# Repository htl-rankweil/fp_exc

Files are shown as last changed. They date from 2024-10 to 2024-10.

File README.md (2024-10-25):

  

# `EXC` - EXtendable Controller (Erweiterbarer Mikrocontroller)

The `EXC` is a microcontroller board with an [ATmega16A](#additional-information)/[ATmega164A](#additional-information). The Board can be powerd over USB or from an external Source (`9-15V`) and used with common Voltages of `3V3` or `5V`. Over the USB port it is also possible to establish a serial (`uart`) connection to a computer. The Board itself offers a `SPI`, `I2C` interface for bus systems, a interface for connection to external interrupts of the microcontroller and a analog interface for reading analog data into the microcontroller. At `DP1` a [Display](#additional-information) can be connected to the board. The available demo firmware offers a quick demonstartion of the board functionallity. Check the [Software](#software) section to get more information.

| Experience | Level |
|:---|:-----:|
| Soldering | ?% |
| Software | ?% |

# Downloads

| Type | File | Description |
|:---:|:---:|:---|
| Schematic | [pdf](https://github.com/0x007E/exc/releases/latest/download/schematic.pdf) / [cadlab](https://cadlab.io/project/28573/main/files) | Schematic files |
| Board | [pdf](https://github.com/0x007E/exc/releases/latest/download/pcb.pdf) / [cadlab](https://cadlab.io/project/28573/main/files) | Board file |
| Drill | [pdf](https://github.com/0x007E/exc/releases/latest/download/drill.pdf) | Drill file |
| Gerber | [zip](https://github.com/0x007E/exc/releases/latest/download/kicad.zip) / [tar](https://github.com/0x007E/exc/releases/latest/download/kicad.tar.gz) | Gerber/Drill files |
| Firmware | [zip](https://github.com/0x007E/exc/releases/latest/download/firmware.zip) / [tar](https://github.com/0x007E/exc/releases/latest/download/firmware.tar.gz) | Firmware for ATmega164A |

# Hardware

The pcb is created with `KiCAD`. All files are built with `github actions` so that they are ready for a production environment.

## PCB

The circuit board is populated on one side. The best way for soldering is within a vapor phase soldering system.

### Top Layer

Top Layer

### Bottom Layer

Bottom Layer

# Configuration

With Jumper `J13` the `EXC` system is getting bus powered (`5V`). If the system runs with `5V` jumper `J12` has to be shorten between `2-3`. When the system is driven by an external source through the step-down converter the system voltage is switchable between `5V` and `3V3` over the slider switch `SW6`. If `3V3` are choosen the jumper `J12` should be shorten between `1-2`.

> Only change the state of `SW6` with disconnected power source. Also check if jumper `J12` is set correctly!

## LEDs/I2C

To enable the LEDs `LED0-1` jumper `J10` has to be shorten. If the `I2C` interface should be used the jumper `J10` has to be removed.

## UART

The UART of the `ATmega164A` can be coupled with the USB/UART bridge or with the external UART interface at connector `J5`. To set the transmission over USB/UART bridge jumper `J1` and `J2` should be shorten between `1-2`. For the external UART interface jumper `J1` and `J2` should be shorten between `2-3`.

## Display

The display can be powerd constantly over `J99` shorten between `2-3` or controllabe over the microcontroller pin `PA2` and `J99` shorten between `1-2`.

# Programming

The Firmware of the `EXC` can be programmed with [Microchip Studio](#additional-information) over ISP with an [ATMEL ICE](#additional-information) connected to `J9` of the `EXC`. It is necessary to power the board from outside either over USB or the external power supply during programming.

## FUSES

| Register  | Value  |
|:---:|:---:|
| `HIGH` | `0xD8` |
| `LOW` | `0xFF` |

# Software

## Dataflow diagram

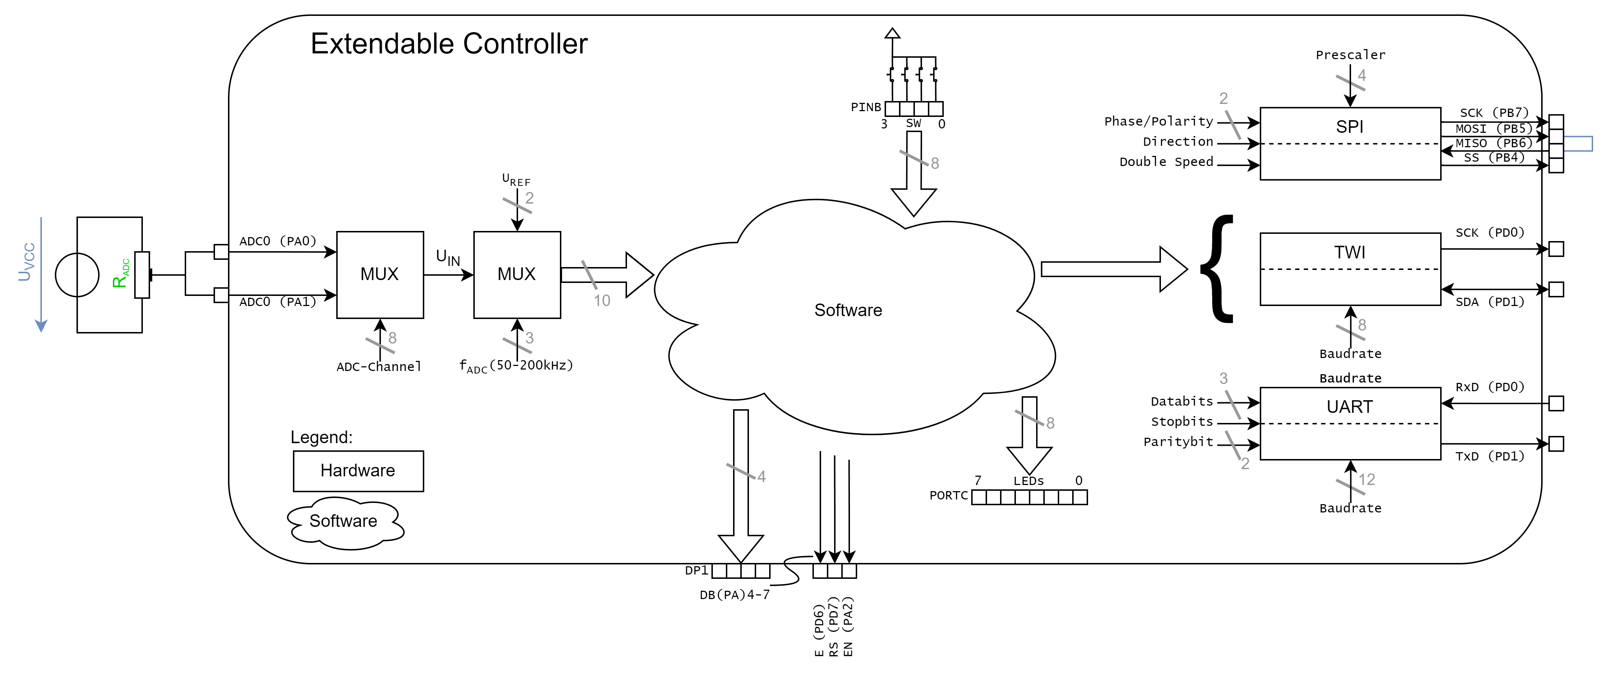
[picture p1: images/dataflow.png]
Dataflow


## Structogram

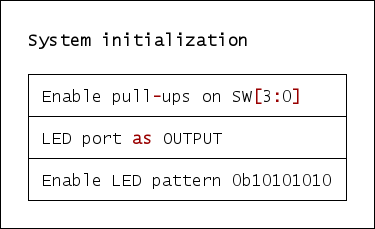
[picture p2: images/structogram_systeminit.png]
Structogram


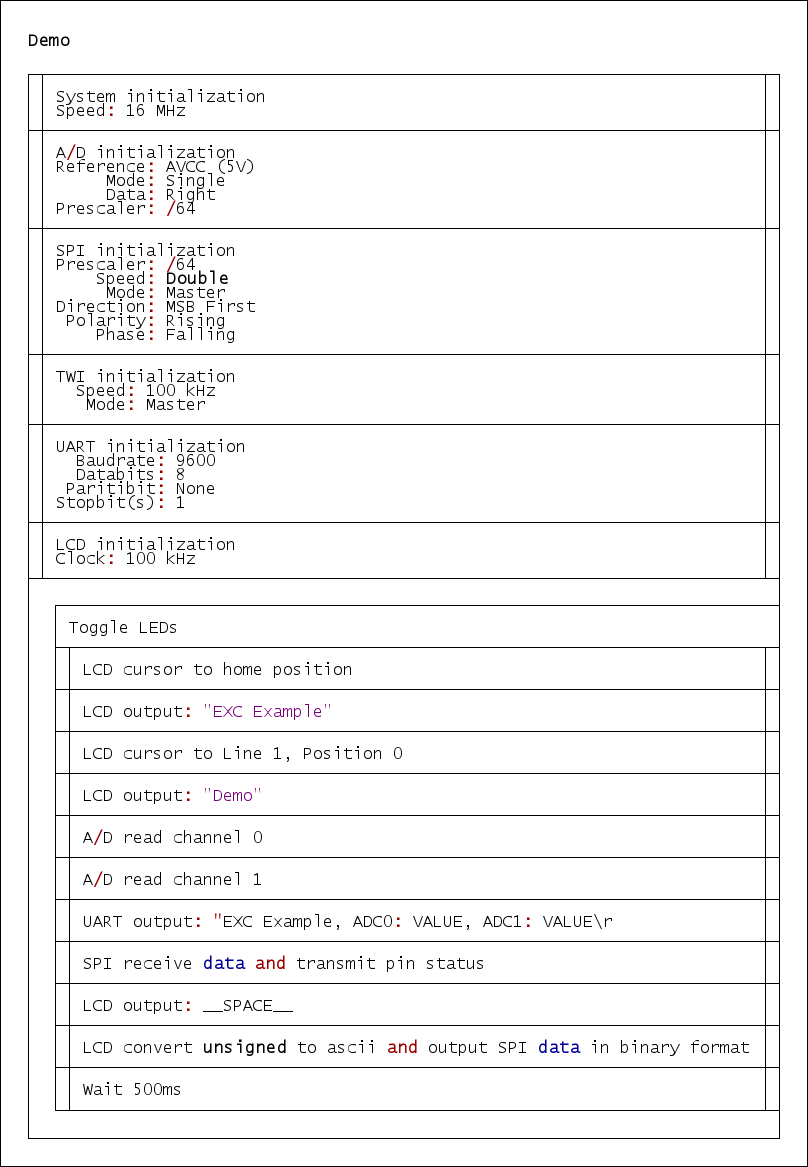
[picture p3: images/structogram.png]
Structogram


# Additional Information

| Type | Link | Description |
|:---:|:---:|:---|
| Display | [web](https://at.rs-online.com/web/p/lcd-displays-monochrom/5326385) | Display for extendable controller |
| Microchip Studio | [web](https://www.microchip.com/en-us/tools-resources/develop/microchip-studio) | Download Page for Microchip Studio |
| Atmel ICE | [pdf](https://ww1.microchip.com/downloads/en/DeviceDoc/Atmel-ICE_UserGuide.pdf) | Atmel ICE Datasheet |
| ATmega16A | [pdf](https://ww1.microchip.com/downloads/en/devicedoc/atmel-8154-8-bit-avr-atmega16a_datasheet.pdf) | Microchip ATmega16A Datasheet
| ATmega164A | [pdf](https://ww1.microchip.com/downloads/en/devicedoc/atmel-8272-8-bit-avr-microcontroller-atmega164a_pa-324a_pa-644a_pa-1284_p_datasheet.pdf) | Microchip ATmega164A Datasheet |

---

R. GAECHTER

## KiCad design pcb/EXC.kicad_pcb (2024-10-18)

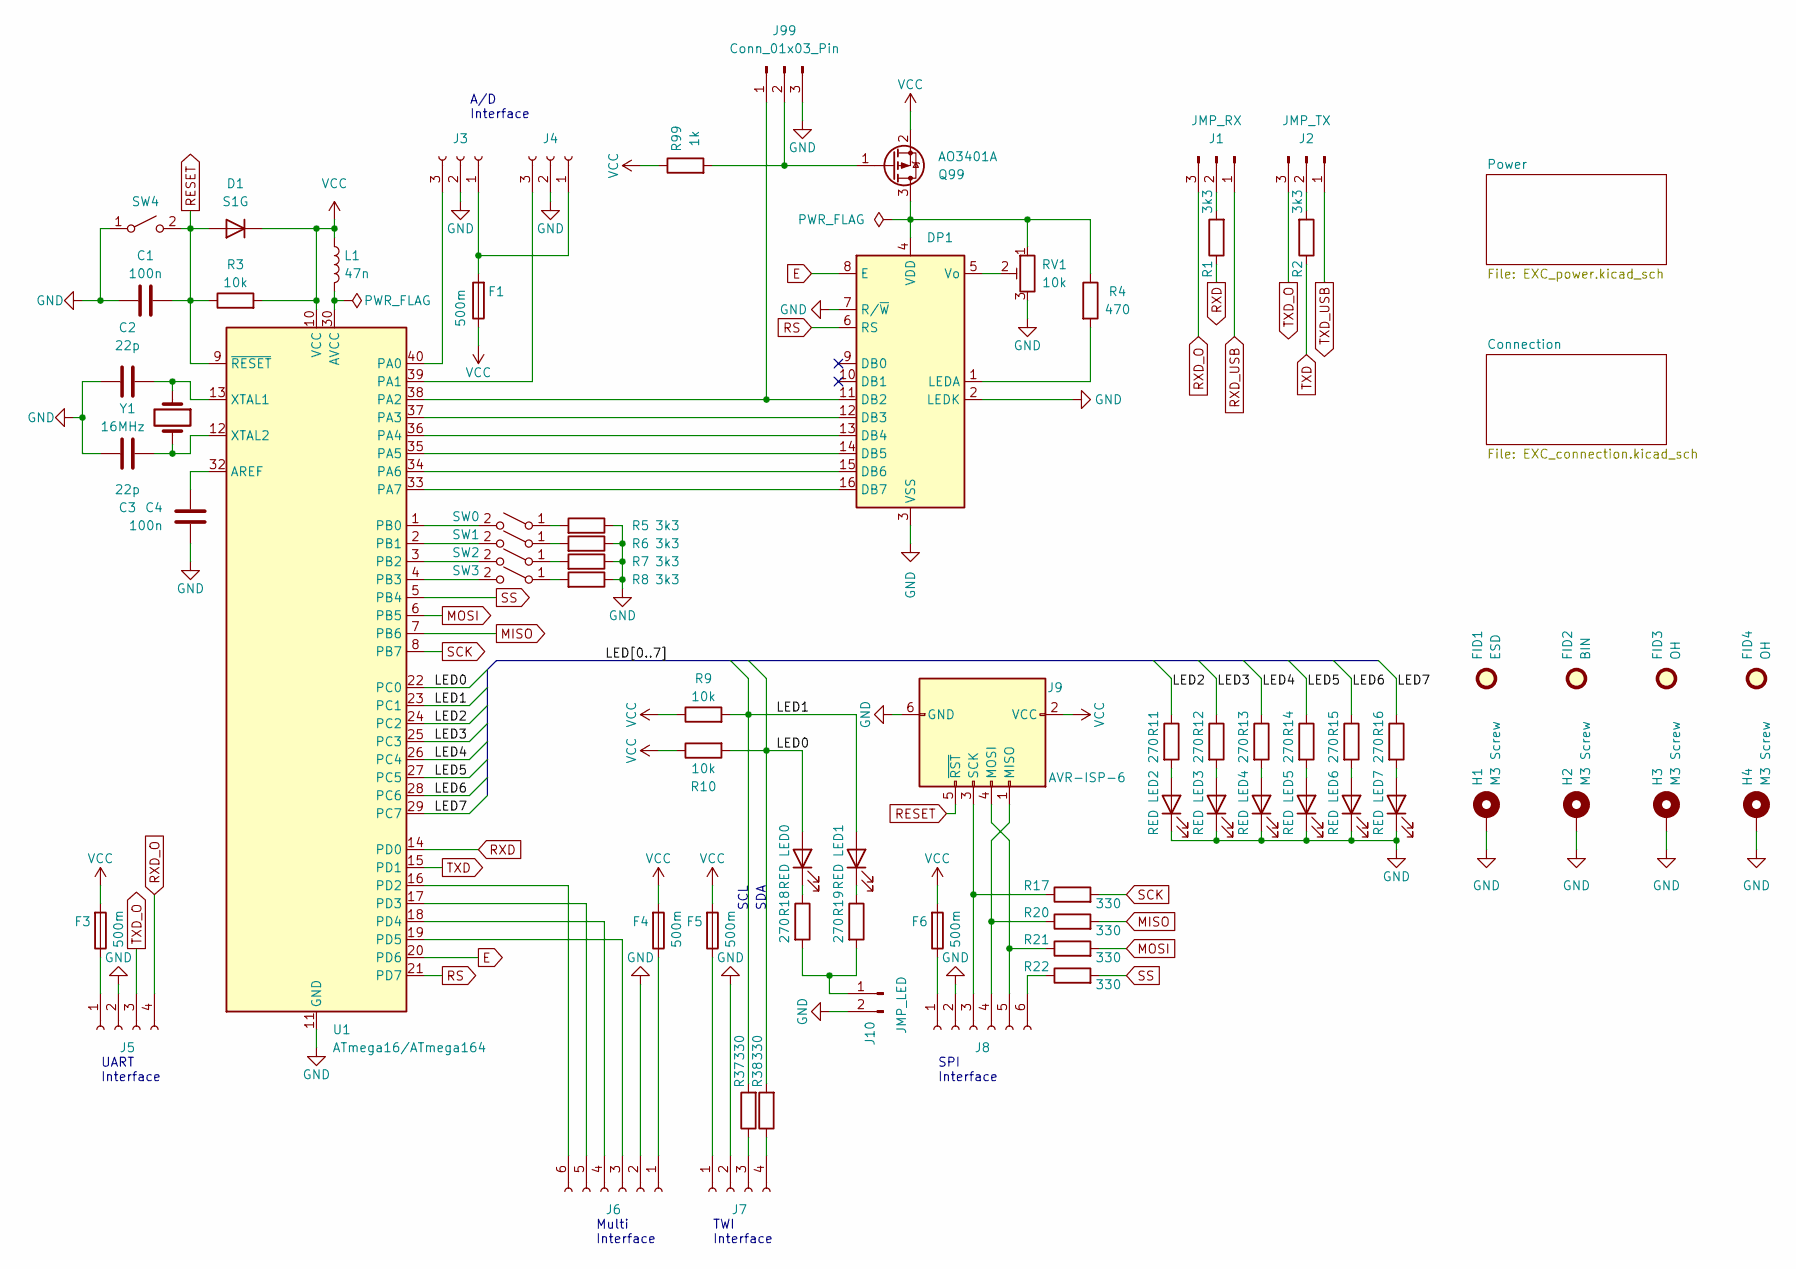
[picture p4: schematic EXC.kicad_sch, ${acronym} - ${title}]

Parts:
C1, C4: 100n; C_1206_3216Metric
C2, C3: 22p; C_1206_3216Metric
D1: S1G; D_MiniMELF
DP1: Displaytech_162A_THT
F1, F3, F4, F5, F6: 500m; Fuse_1206_3216Metric
FID1: ESD; ESD-Logo_6.6x6mm_SilkScreen
FID2: BIN; WEEE-Logo_4.2x6mm_SilkScreen
FID3: OH; OSHW-Logo_5.7x6mm_SilkScreen
FID4: OH; QR_0x007e
H1, H2, H3, H4: M3 Screw; MountingHole_3.2mm_M3_DIN965_Pad
J1: JMP_RX; PinHeader_1x03_P2.54mm_Vertical
J2: JMP_TX; PinHeader_1x03_P2.54mm_Vertical
J3, J4: Conn_01x03_Socket; PinSocket_1x03_P2.54mm_Vertical
J5, J7: Conn_01x04_Socket; PinSocket_1x04_P2.54mm_Vertical
J6, J8: Conn_01x06_Socket; PinSocket_1x06_P2.54mm_Vertical
J9: AVR-ISP-6; PinHeader_2x03_P2.54mm_Vertical
J10: JMP_LED; PinHeader_1x02_P2.54mm_Vertical
J99: Conn_01x03_Pin; PinHeader_1x03_P2.54mm_Horizontal
L1: 47n; L_1206_3216Metric_Pad1.42x1.75mm_HandSolder
LED0, LED1, LED2, LED3, LED4, LED5, LED6, LED7: RED; LED_1206_3216Metric
Q99: AO3401A; SOT-23
R1, R2, R5, R6, R7, R8: 3k3; R_1206_3216Metric
R3, R9, R10: 10k; R_1206_3216Metric
R4: 470; R_1206_3216Metric
R11, R12, R13, R14, R15, R16, R18, R19: 270; R_1206_3216Metric
R17, R20, R21, R22, R37, R38: 330; R_1206_3216Metric
R99: 1k; R_1206_3216Metric
RV1: 10k; Potentiometer_Bourns_3266W_Vertical
SW0, SW1, SW2, SW3, SW4: SW_SPST; SW_SPST_PTS645
U1: ATmega16/ATmega164; DIP-40_W15.24mm_LongPads
Y1: 16MHz; Crystal_SMD_Abracon_ABM3-2Pin_5.0x3.2mm

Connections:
/LED0: LED0.2 (A), R10.2, R38.2, U1.22 (PC0)
/LED1: LED1.2 (A), R9.2, R37.2, U1.23 (PC1)
/LED2: R11.1, U1.24 (PC2)
/LED3: R12.1, U1.25 (PC3)
/LED4: R13.1, U1.26 (PC4)
/LED5: R14.1, U1.27 (PC5)
/LED6: R15.1, U1.28 (PC6)
/LED7: R16.1, U1.29 (PC7)
E: DP1.8 (E), U1.20 (PD6)
GND: C1.1, C2.1, C3.1, C4.2, DP1.2 (LEDK), DP1.3 (VSS), DP1.7 (R/~W), H1.1, H2.1, H3.1, H4.1, J3.2, J4.2, J5.2, J6.2, J7.2, J8.2, J9.6 (GND), J10.2, J99.3, LED2.1 (K), LED3.1 (K), LED4.1 (K), LED5.1 (K), LED6.1 (K), LED7.1 (K), R5.1, R6.1, R7.1, R8.1, RV1.3, SW4.1 (A), U1.11 (GND), U1.31 (GND); also elsewhere on the board
MISO: R20.2, U1.7 (PB6)
MOSI: R21.2, U1.6 (PB5)
unnamed: DP1.11 (DB2), J99.1, U1.38 (PA2)
unnamed: DP1.12 (DB3), U1.37 (PA3)
unnamed: DP1.13 (DB4), U1.36 (PA4)
unnamed: DP1.14 (DB5), U1.35 (PA5)
unnamed: DP1.15 (DB6), U1.34 (PA6)
unnamed: DP1.16 (DB7), U1.33 (PA7)
unnamed: DP1.1 (LEDA), R4.2
unnamed: DP1.4 (VDD), Q99.3 (D), R4.1, RV1.1
unnamed: DP1.5 (Vo), RV1.2
unnamed: J1.2, R1.2
unnamed: J2.2, R2.2
unnamed: F1.2, J3.1, J4.1
unnamed: J3.3, U1.40 (PA0)
unnamed: J4.3, U1.39 (PA1)
unnamed: F3.1, J5.1
unnamed: F4.1, J6.1
unnamed: J6.3, U1.19 (PD5)
unnamed: J6.4, U1.18 (PD4)
unnamed: J6.5, U1.17 (PD3)
unnamed: J6.6, U1.16 (PD2)
unnamed: F5.1, J7.1
unnamed: J7.3, R37.1
unnamed: J7.4, R38.1
unnamed: F6.1, J8.1
unnamed: J8.3, J9.3 (SCK), R17.1
unnamed: J8.4, J9.1 (MISO), R20.1
unnamed: J8.5, J9.4 (MOSI), R21.1
unnamed: J8.6, R22.1
unnamed: J10.1, R18.2, R19.2
unnamed: J99.2, Q99.1 (G), R99.2
unnamed: LED0.1 (K), R18.1
unnamed: LED1.1 (K), R19.1
unnamed: LED2.2 (A), R11.2
unnamed: LED3.2 (A), R12.2
unnamed: LED4.2 (A), R13.2
unnamed: LED5.2 (A), R14.2
unnamed: LED6.2 (A), R15.2
unnamed: LED7.2 (A), R16.2
unnamed: R5.2, SW0.1 (A)
unnamed: SW0.2 (B), U1.1 (PB0)
unnamed: R6.2, SW1.1 (A)
unnamed: SW1.2 (B), U1.2 (PB1)
unnamed: R7.2, SW2.1 (A)
unnamed: SW2.2 (B), U1.3 (PB2)
unnamed: R8.2, SW3.1 (A)
unnamed: SW3.2 (B), U1.4 (PB3)
unnamed: C4.1, U1.32 (AREF)
unnamed: L1.2, U1.30 (AVCC)
unnamed: C2.2, U1.13 (XTAL1), Y1.1
unnamed: C3.2, U1.12 (XTAL2), Y1.2
RESET: C1.2, D1.2 (A), J9.5 (~RST), R3.1, SW4.2 (B), U1.9 (~RESET)
RS: DP1.6 (RS), U1.21 (PD7)
RXD: R1.1, U1.14 (PD0)
RXD_O: J1.3, J5.4
RXD_USB: J1.1; also elsewhere on the board
SCK: R17.2, U1.8 (PB7)
SS: R22.2, U1.5 (PB4)
TXD: R2.1, U1.15 (PD1)
TXD_O: J2.3, J5.3
TXD_USB: J2.1; also elsewhere on the board
VCC: D1.1 (K), F1.1, F3.2, F4.2, F5.2, F6.2, J9.2 (VCC), L1.1, Q99.2 (S), R3.2, R9.1, R10.1, R99.1, U1.10 (VCC); also elsewhere on the board

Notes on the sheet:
Multi Interface
UART Interface
A/D Interface
TWI Interface
SCL
SDA
SPI Interface

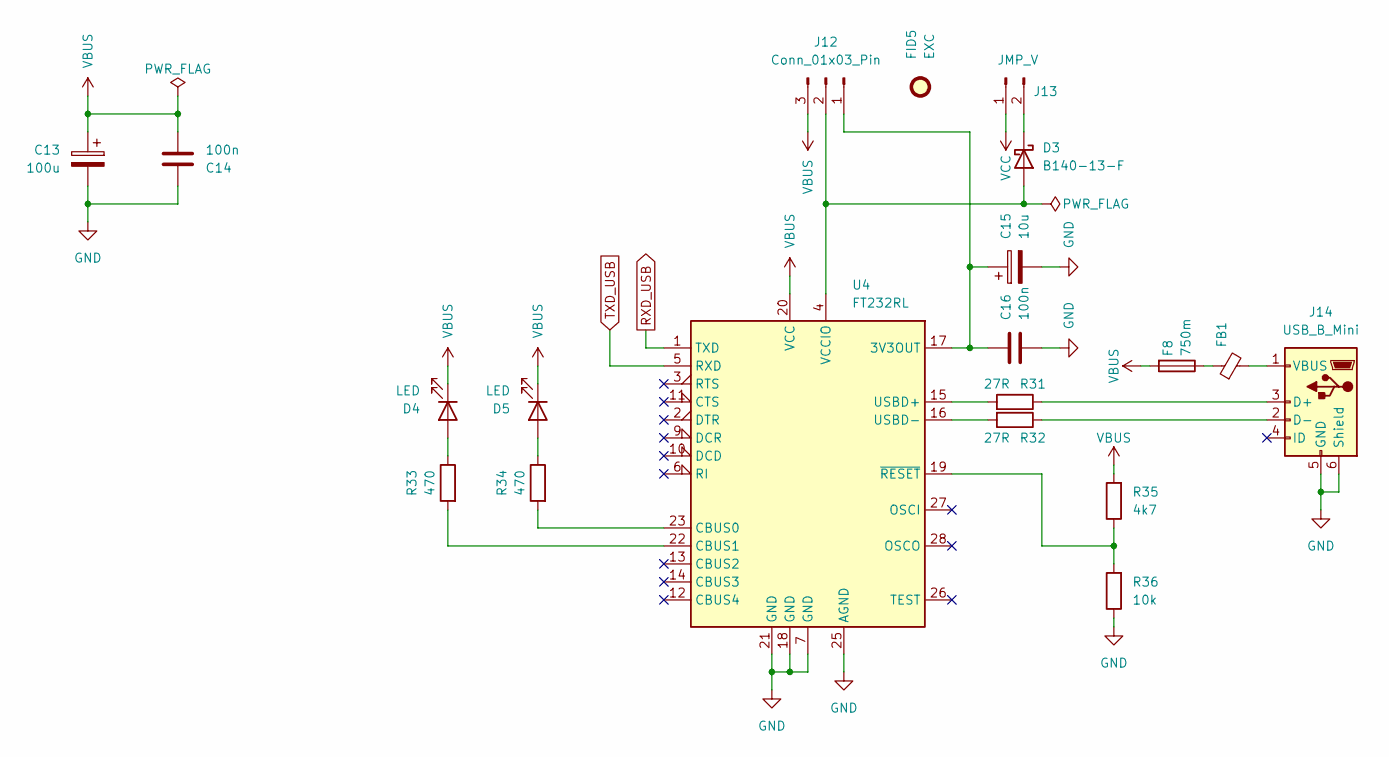
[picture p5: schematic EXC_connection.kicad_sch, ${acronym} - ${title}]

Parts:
C13: 100u; CP_Elec_5x5.4
C14, C16: 100n; C_1206_3216Metric
C15: 10u; CP_Elec_5x5.4
D3: B140-13-F; D_SMA
D4, D5: LED; LED_1206_3216Metric
F8: 750m; Fuse_1206_3216Metric
FB1: FerriteBead_Small; L_1206_3216Metric
FID5: EXC; Symbol_Attention_2x2mm_SilkScreen
J12: Conn_01x03_Pin; PinHeader_1x03_P2.54mm_Vertical
J13: JMP_V; PinHeader_1x02_P2.54mm_Vertical
J14: USB_B_Mini; USB_Mini-B_Lumberg_2486_01_Horizontal
R31, R32: 27R; R_1206_3216Metric
R33, R34: 470; R_1206_3216Metric
R35: 4k7; R_1206_3216Metric
R36: 10k; R_1206_3216Metric
U4: FT232RL; SSOP-28_5.3x10.2mm_P0.65mm

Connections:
GND: C13.2, C14.2, C15.2, C16.1, J14.5 (GND), J14.6 (Shield), R36.1, U4.7 (GND), U4.18 (GND), U4.21 (GND), U4.25 (AGND); also elsewhere on the board
unnamed: D3.2 (A), J12.2, U4.4 (VCCIO)
unnamed: D3.1 (K), J13.2
unnamed: D4.2 (A), R33.1
unnamed: D5.2 (A), R34.1
unnamed: F8.1, FB1.1
unnamed: C15.1, C16.2, J12.1, U4.17 (3V3OUT)
unnamed: J14.3 (D+), R31.1
unnamed: J14.2 (D-), R32.1
unnamed: FB1.2, J14.1 (VBUS)
unnamed: R34.2, U4.23 (CBUS0)
unnamed: R33.2, U4.22 (CBUS1)
unnamed: R31.2, U4.15 (USBD+)
unnamed: R32.2, U4.16 (USBD-)
unnamed: R35.1, R36.2, U4.19 (~RESET)
RXD_USB: U4.1 (TXD); also elsewhere on the board
TXD_USB: U4.5 (RXD); also elsewhere on the board
VBUS: C13.1, C14.1, D4.1 (K), D5.1 (K), F8.2, J12.3, R35.2, U4.20 (VCC)
VCC: J13.1; also elsewhere on the board

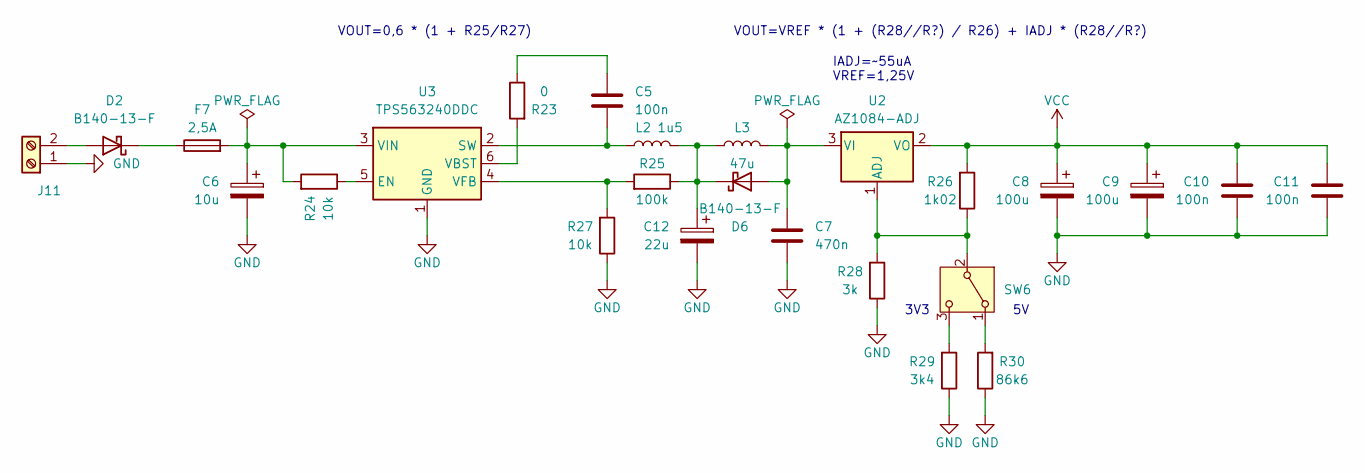
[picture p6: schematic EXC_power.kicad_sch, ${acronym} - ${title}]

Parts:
C5, C10, C11: 100n; C_1206_3216Metric
C6: 10u; CP_Elec_5x5.4
C7: 470n; C_1206_3216Metric
C8, C9: 100u; CP_Elec_5x5.4
C12: 22u; CP_Elec_5x5.4
D2, D6: B140-13-F; D_SMA
F7: 2,5A; Fuse_1812_4532Metric
J11: Screw_Terminal_01x02; TerminalBlock_RND_205-00001_1x02_P5.00mm_Horizontal
L2: 1u5; L_Bourns_SRP7028A_7.3x6.6mm
L3: 47u; L_Bourns_SRN8040TA
R23: 0; R_1206_3216Metric
R24, R27: 10k; R_1206_3216Metric
R25: 100k; R_1206_3216Metric
R26: 1k02; R_1206_3216Metric
R28: 3k; R_1206_3216Metric
R29: 3k4; R_1206_3216Metric
R30: 86k6; R_1206_3216Metric
SW6: SW_SPDT; SW_SPDT_CK_JS102011SAQN
U2: AZ1084-ADJ; TO-263-2
U3: TPS563240DDC; SOT-23-6

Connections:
GND: C6.2, C7.1, C8.2, C9.2, C10.1, C11.1, C12.2, J11.1, R27.1, R28.1, R29.1, R30.1, U3.1 (GND); also elsewhere on the board
unnamed: C5.2, R23.1
unnamed: D2.2 (A), J11.2
unnamed: D2.1 (K), F7.1
unnamed: C7.2, D6.2 (A), L3.2, U2.3 (VI)
unnamed: C12.1, D6.1 (K), L2.2, L3.1, R25.1
unnamed: R30.2, SW6.1 (A)
unnamed: R26.1, R28.2, SW6.2 (B), U2.1 (ADJ)
unnamed: R29.2, SW6.3 (C)
unnamed: R24.1, U3.5 (EN)
unnamed: C5.1, L2.1, U3.2 (SW)
unnamed: R23.2, U3.6 (VBST)
unnamed: R25.2, R27.2, U3.4 (VFB)
unnamed: C6.1, F7.2, R24.2, U3.3 (VIN)
VCC: C8.1, C9.1, C10.2, C11.2, R26.2, U2.2 (VO); also elsewhere on the board

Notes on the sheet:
VOUT=0,6 * (1 + R25/R27)
VOUT=VREF * (1 + (R28//R?) / R26) + IADJ * (R28//R?)
3V3
IADJ=~55uA VREF=1,25V

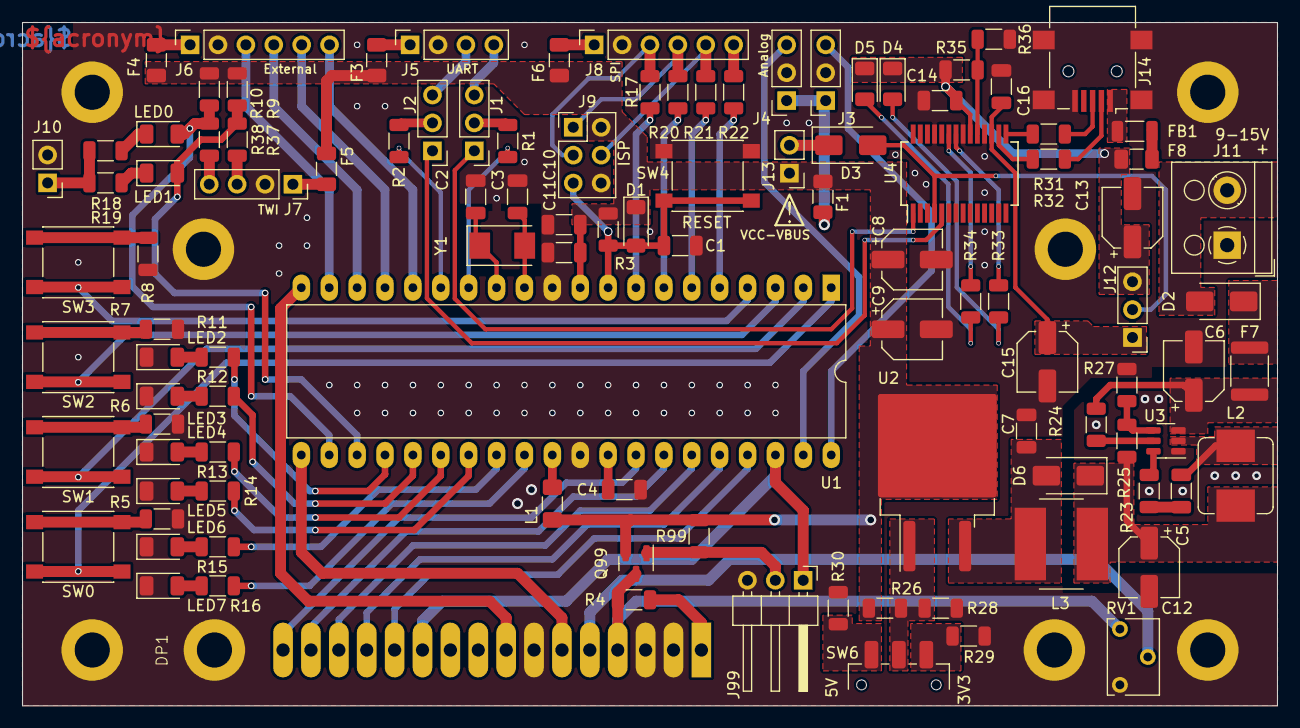
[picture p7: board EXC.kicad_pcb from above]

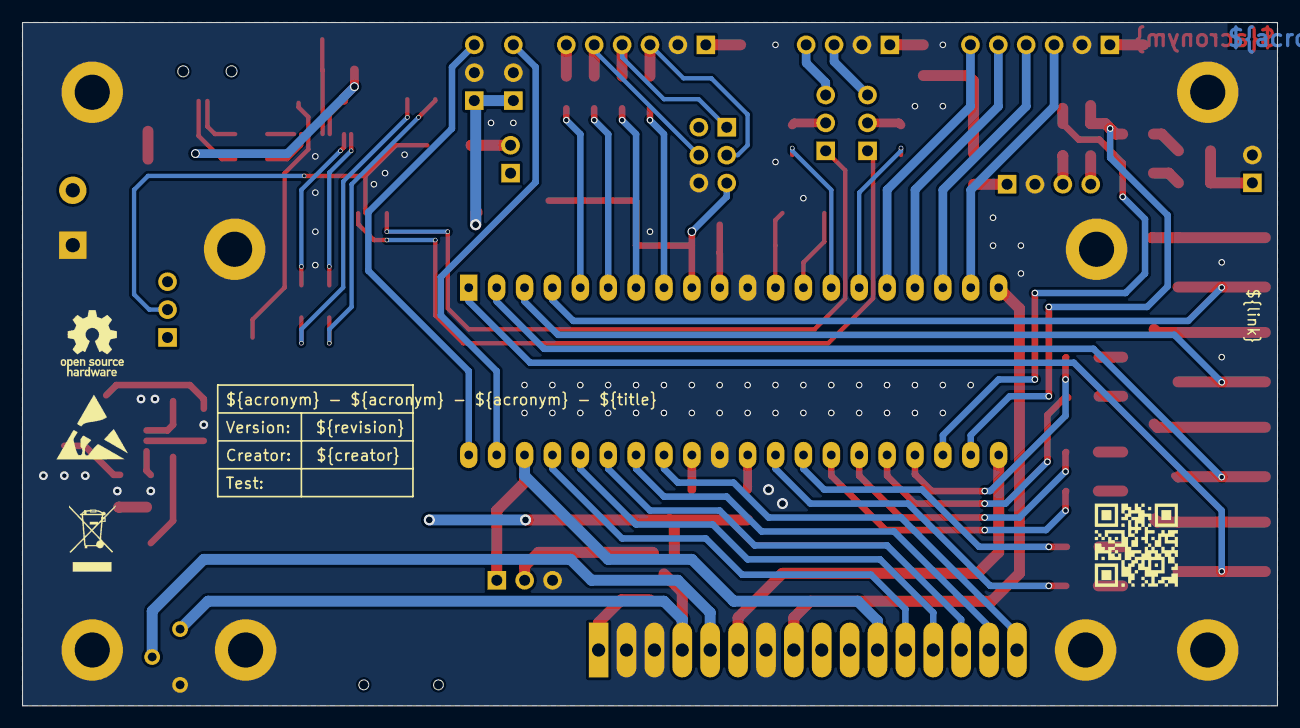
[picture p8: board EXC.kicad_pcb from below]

Board: 2 copper layers, 114.3 x 62.2 mm, 118 parts (4 on the bottom side), 101 nets.

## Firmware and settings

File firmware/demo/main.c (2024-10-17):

#define F_CPU 16000000UL

#include <avr/io.h>
#include <util/delay.h>

#include "../lib/adc/adc.h"
#include "../lib/spi/spi.h"
#include "../lib/twi/twi.h"
#include "../lib/uart/uart.h"
#include "../lib/lcd/lcd.h"

static void system_init()
{
	PORTB = 0x0F;	// Enable Pullup
	
	DDRC = 0xFF;	// PORT as Output
	PORTC = 0xAA;	// LEDs on
}

int main(void)
{
	system_init();
	adc_init();
	spi_init(SPI_Master, SPI_MSB, SPI_Rising, SPI_Falling);
	twi_init(TWI_Master);
	uart_init();
	lcd_init();
	
    while (1) 
    {
		PORTC ^= 0xFF;
		
		lcd_home();
		lcd_string("EXC Example");
		lcd_cursor(0,1);
		lcd_string("Demo");
		
		adc_channel(ADC_CH0);
		unsigned int adc0 = adc_read();
		
		adc_channel(ADC_CH1);
		unsigned int adc1 = adc_read();
		
		printf("EXC Example, ADC0: %4u, ADC1: %4u\r", adc0, adc1);
		
		unsigned char data = spi_transfer(PINB);
		
		lcd_char(' ');
		lcd_ul2ascii((0x0F & ~data), LCD_Binary, 8);
		
		_delay_ms(500);
    }
}

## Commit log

2024-10-17 Add courtyard overlap filter
2024-10-17 Change switch SW6
    [EXC.kicad_pcb, EXC.kicad_sch, EXC_power.kicad_sch]
2024-10-17 Add display socket
    [EXC.kicad_pcb]
2024-10-18 Change text position
    [EXC.kicad_pcb]
2024-10-25 Add fuses

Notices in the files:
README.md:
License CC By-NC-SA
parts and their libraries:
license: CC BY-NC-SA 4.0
